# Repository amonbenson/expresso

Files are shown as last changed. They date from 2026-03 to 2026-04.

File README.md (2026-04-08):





# Expresso

An open source USB&ndash;Midi&ndash;Expression pedal converter.

⚠️ Please note: This project is currently under heavy development and not yet functional. ⚠️

✔️ Supports sustain pedals of any polarity<br>
✔️ Supports any kind of three-pin analog expression pedal<br>
✔️ Pedal state can be output to both Din- or USB-Midi<br>
✔️ Can be used as a classic USB-Din-Midi adapter<br>

... to be continued.

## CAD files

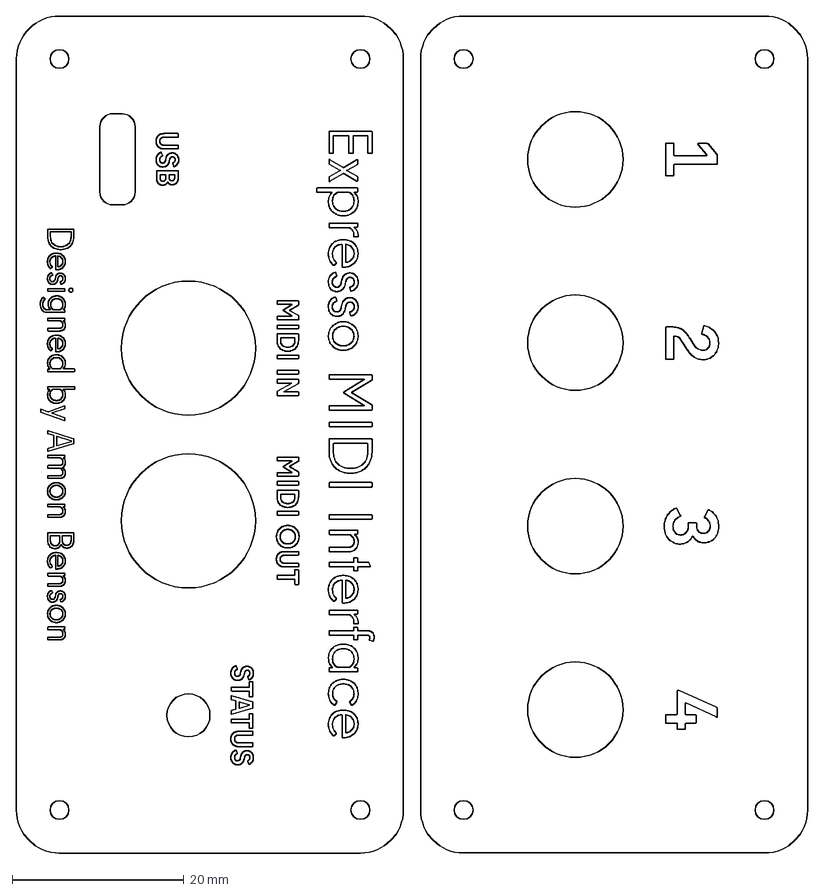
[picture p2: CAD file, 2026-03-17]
hw/enclosure/Expresso Enclosure Laser Cut Parts Projection.dxf
92.0 x 97.3 mm

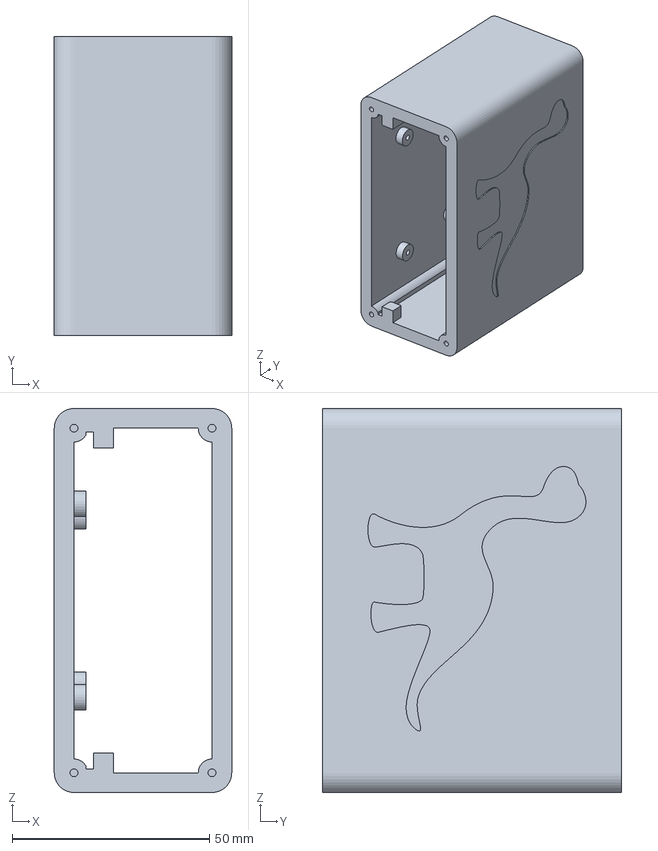
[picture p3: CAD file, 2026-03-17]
hw/enclosure/fabrication/Expresso Enclosure.3mf
45.0 x 75.7 x 97.3 mm

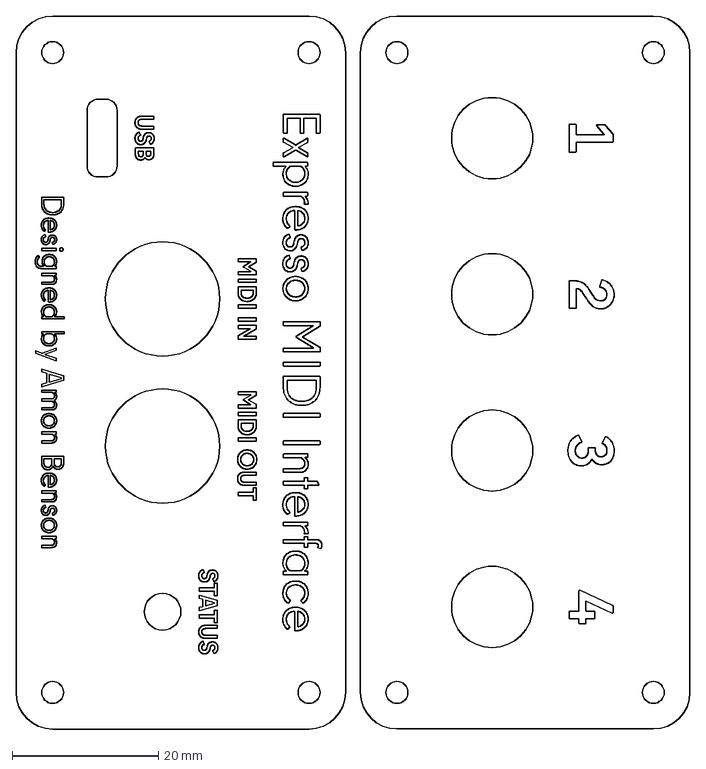
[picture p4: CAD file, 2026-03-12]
hw/Expresso Enclosure Laser Cut Parts Projection.dxf
92.0 x 97.3 mm

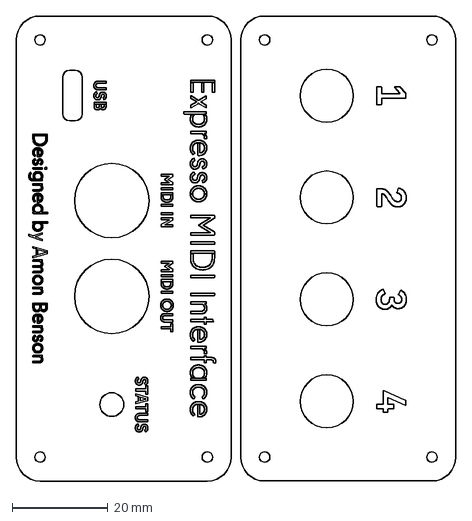
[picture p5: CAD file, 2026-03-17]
hw/enclosure/Expresso Enclosure Laser Cut Parts.dxf
92.0 x 97.3 mm

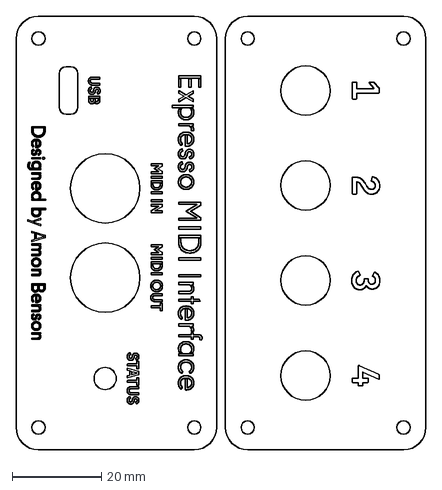
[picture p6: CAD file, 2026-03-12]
hw/Expresso Enclosure Laser Cut Parts.dxf
92.0 x 97.3 mm

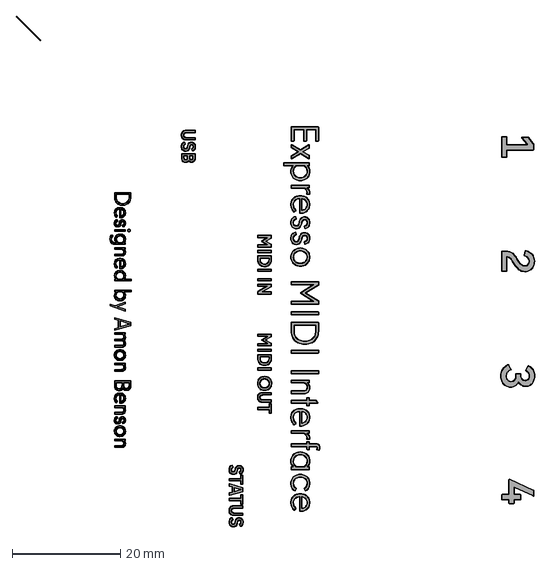
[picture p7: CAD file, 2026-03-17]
hw/enclosure/Expresso Enclosure Laser Cut Engravings.dxf
96.0 x 94.5 mm

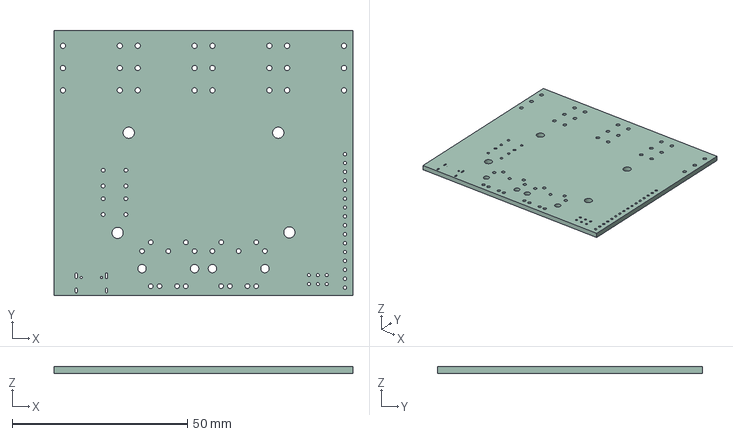
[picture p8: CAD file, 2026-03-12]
hw/Expresso.step
85.3 x 75.7 x 1.87 mm

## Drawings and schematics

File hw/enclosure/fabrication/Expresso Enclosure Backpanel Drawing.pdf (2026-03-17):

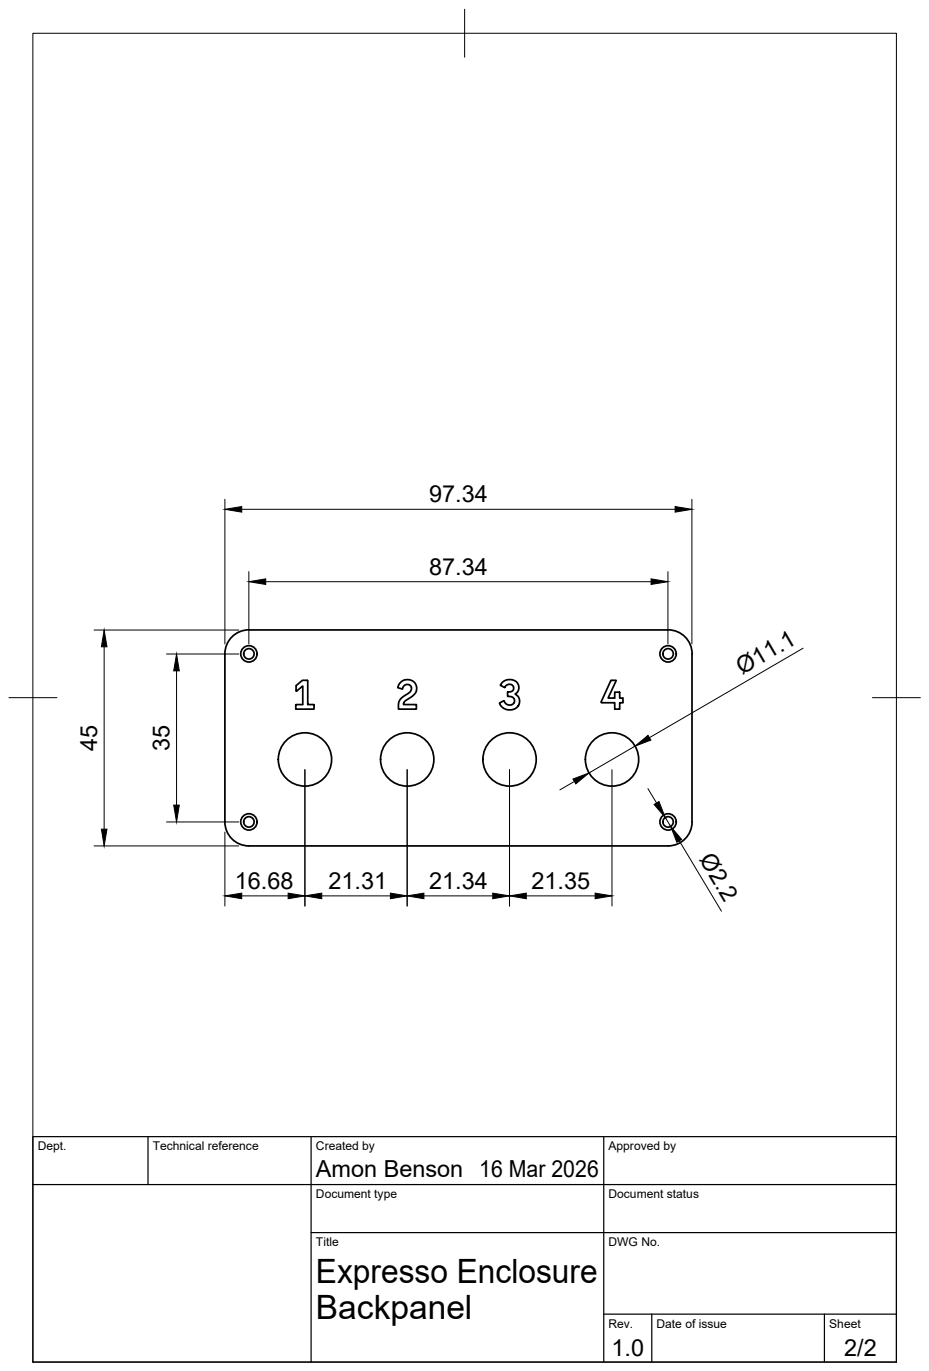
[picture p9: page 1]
Amon Benson 45

Dept. | Technical reference | Created by 16 Mar 2026 | Approved by

Document type | Document status

Title Expresso Enclosure Backpanel | DWG No.

Rev. 1.0 | Date of issue | Sheet 2/2

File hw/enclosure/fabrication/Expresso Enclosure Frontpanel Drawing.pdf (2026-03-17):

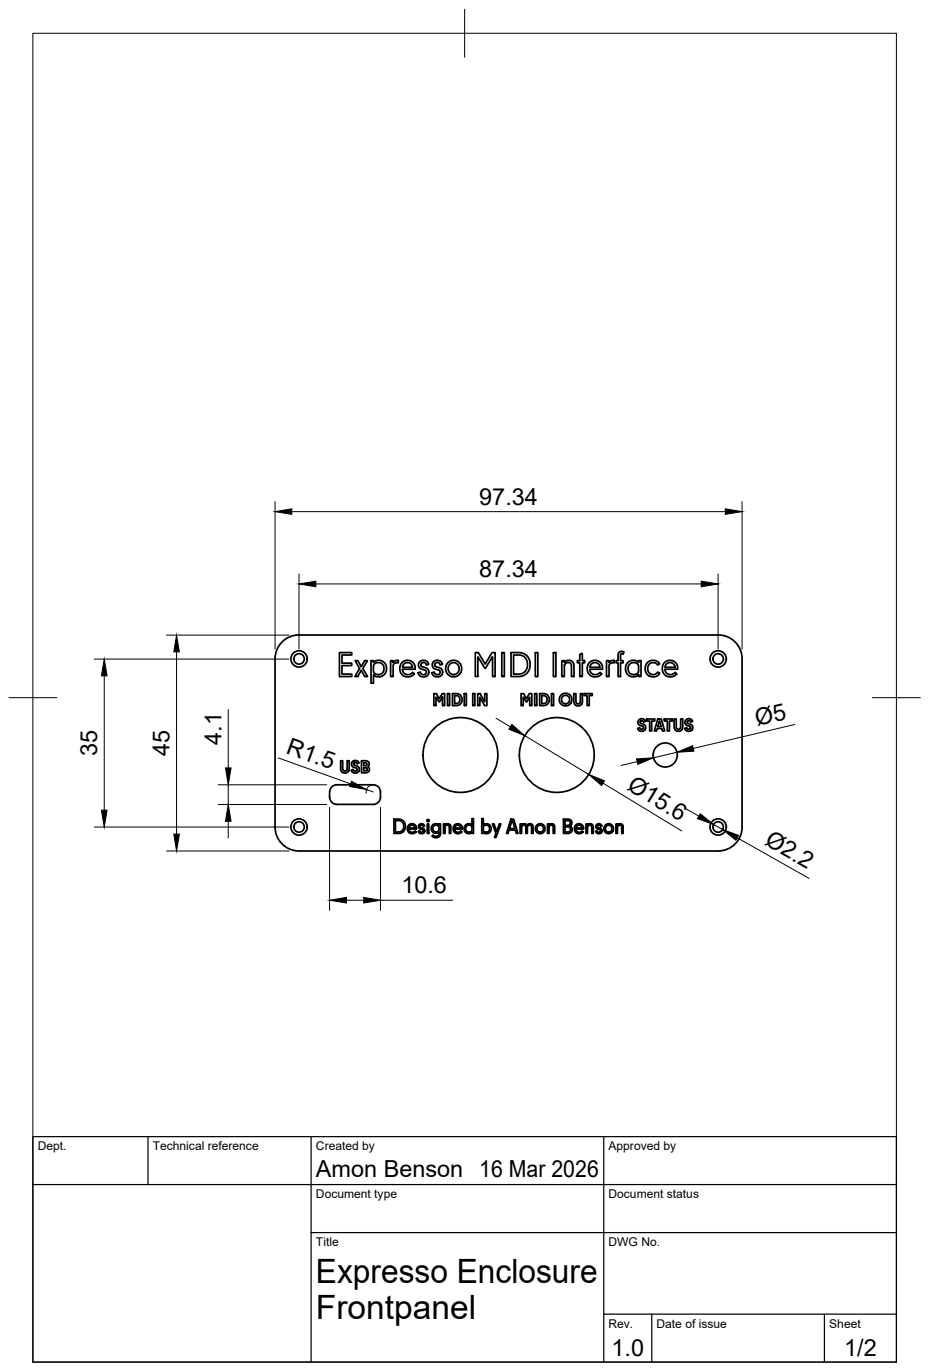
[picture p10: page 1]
Amon Benson 45 Ø15.6 35R1.5

Dept. | Technical reference | Created by 16 Mar 2026 | Approved by

Document type | Document status

Title Expresso Enclosure Frontpanel | DWG No.

Rev. 1.0 | Date of issue | Sheet 1/2

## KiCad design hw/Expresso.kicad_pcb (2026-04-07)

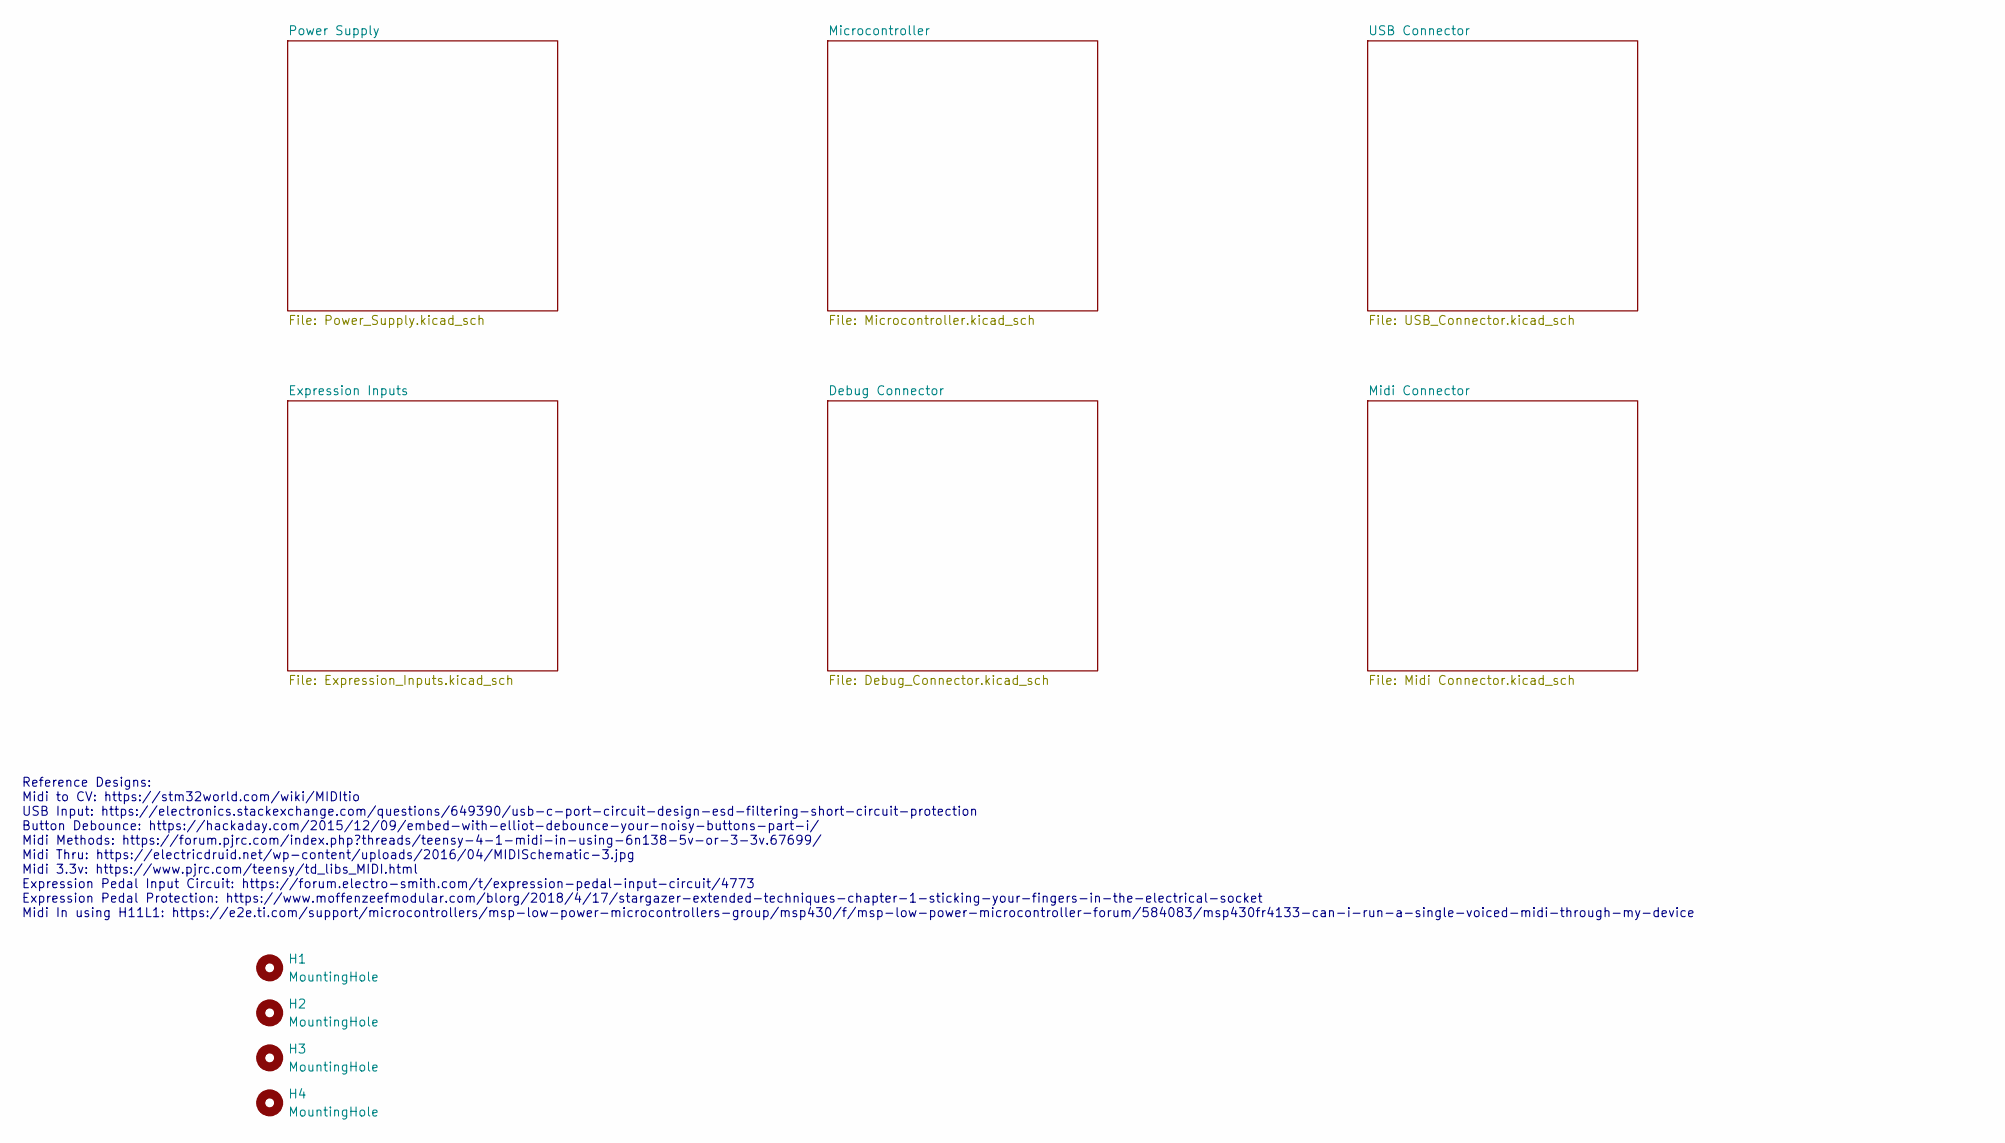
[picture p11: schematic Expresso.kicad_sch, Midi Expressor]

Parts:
H1, H2, H3, H4: MountingHole; MountingHole_3.2mm_M3

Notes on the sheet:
Reference Designs: Midi to CV: https://stm32world.com/wiki/MIDItio USB Input: https://electronics.stackexchange.com/questions/649390/usb-c-port-circuit-design-esd-filtering-short-circuit-protection Button Debounce: https://hackaday.com/2015/12/09/embed-with-elliot-debounce-your-noisy-buttons-part-i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

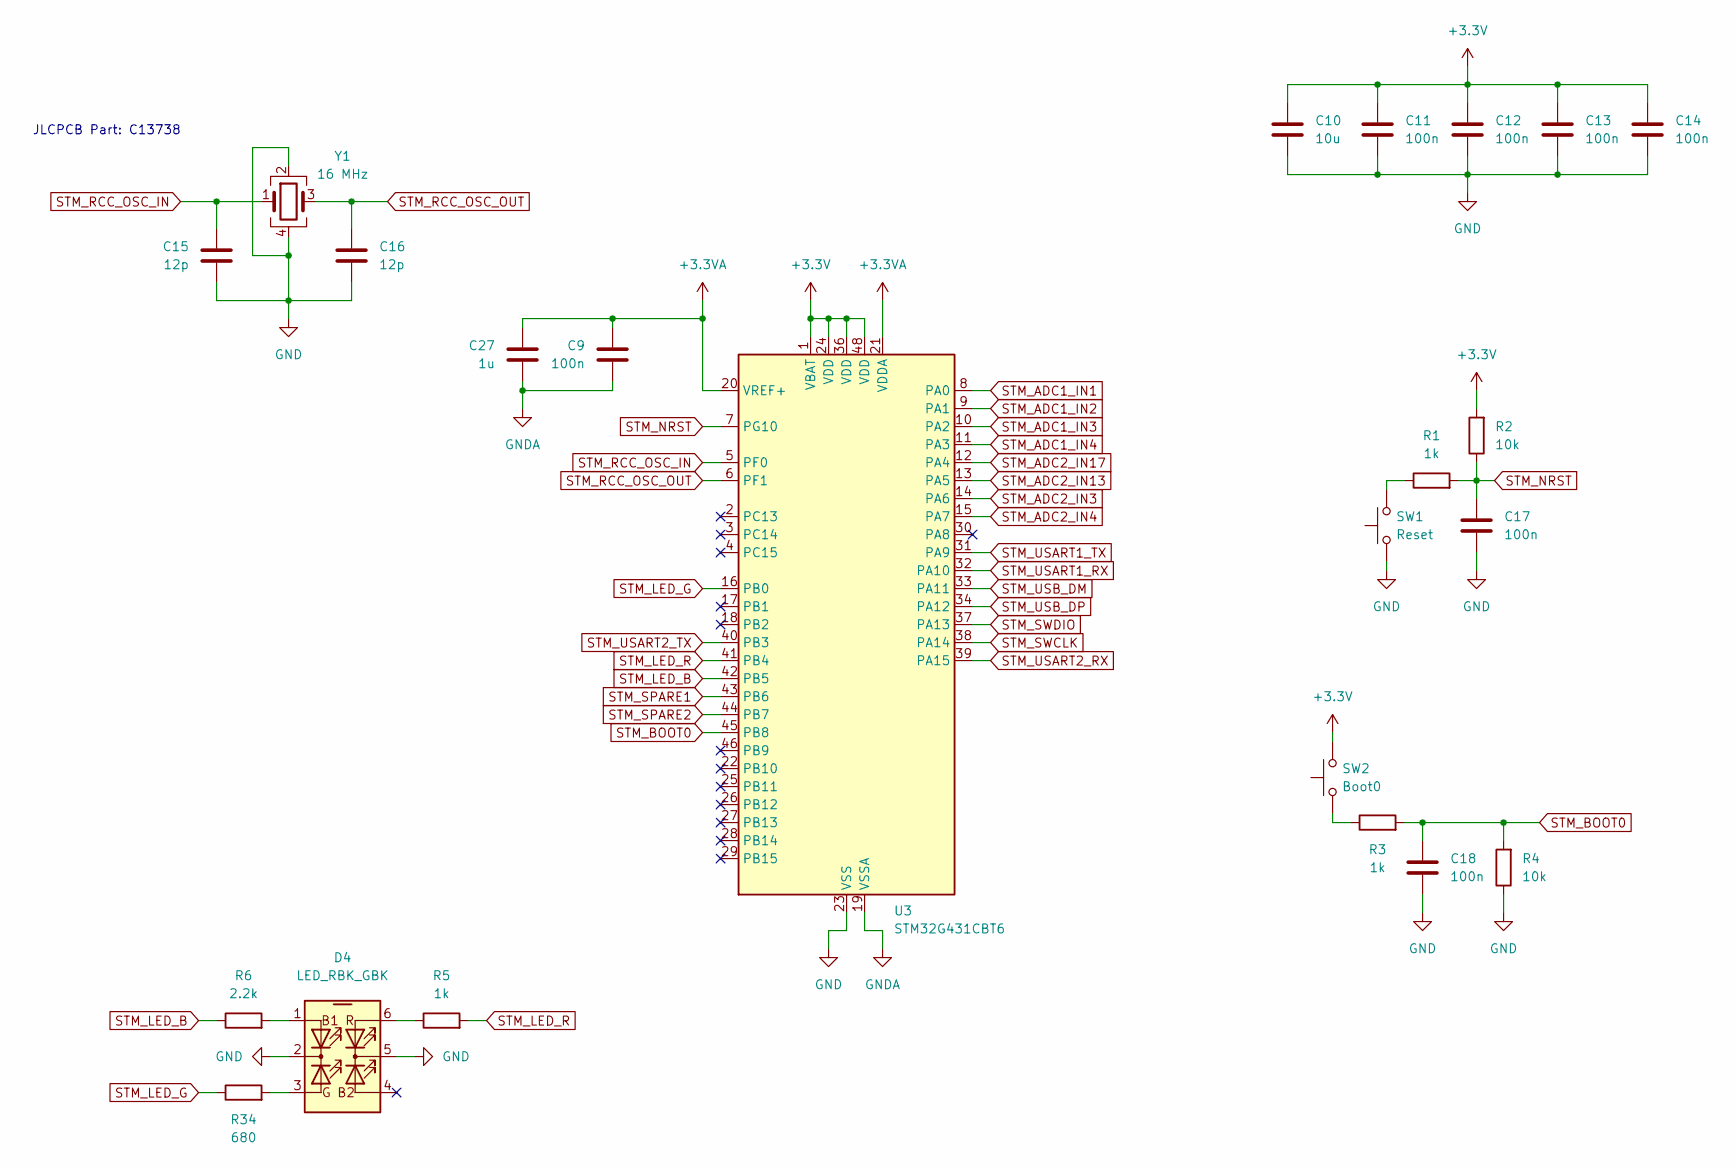
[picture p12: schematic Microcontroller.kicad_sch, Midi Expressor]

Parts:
C9, C11, C12, C13, C14, C17, C18: 100n; C_0603_1608Metric; LCSC C14663
C10: 10u; C_0603_1608Metric; LCSC C19702
C15, C16: 12p; C_0603_1608Metric; LCSC C38523
C27: 1u; C_0603_1608Metric; LCSC C15849
D4: LED_RBK_GBK; LED_D5.0mm_6Pin
R1, R3, R5: 1k; R_0603_1608Metric; LCSC C21190
R2, R4: 10k; R_0603_1608Metric; LCSC C25804
R6: 2.2k; R_0603_1608Metric; LCSC C4190
R34: 680; R_0603_1608Metric; LCSC C23228
SW1: Reset; SW_PUSH_6mm
SW2: Boot0; SW_PUSH_6mm
U3: STM32G431CBT6; LQFP-48_7x7mm_P0.5mm; LCSC C529355
Y1: 16 MHz; Crystal_SMD_3225-4Pin_3.2x2.5mm; LCSC C13738

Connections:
+3.3V: C10.1, C11.1, C12.1, C13.1, C14.1, R2.2, SW2.2, U3.1 (VBAT), U3.24 (VDD), U3.36 (VDD), U3.48 (VDD); also elsewhere on the board
+3.3VA: C9.1, C27.1, U3.20 (VREF+), U3.21 (VDDA); also elsewhere on the board
GND: C10.2, C11.2, C12.2, C13.2, C14.2, C15.2, C16.2, C17.2, C18.2, D4.2 (K1), D4.5 (K2), R4.1, SW1.1, U3.23 (VSS), U3.35 (VSS), U3.47 (VSS), Y1.2, Y1.4; also elsewhere on the board
GNDA: C9.2, C27.2, U3.19 (VSSA); also elsewhere on the board
unnamed: D4.1 (B1A), R6.2
unnamed: D4.3 (GA), R34.2
unnamed: D4.6 (RA), R5.1
unnamed: R1.1, SW1.2
unnamed: R3.1, SW2.1
STM_ADC1_IN1: U3.8 (PA0); also elsewhere on the board
STM_ADC1_IN2: U3.9 (PA1); also elsewhere on the board
STM_ADC1_IN3: U3.10 (PA2); also elsewhere on the board
STM_ADC1_IN4: U3.11 (PA3); also elsewhere on the board
STM_ADC2_IN3: U3.14 (PA6); also elsewhere on the board
STM_ADC2_IN4: U3.15 (PA7); also elsewhere on the board
STM_ADC2_IN13: U3.13 (PA5); also elsewhere on the board
STM_ADC2_IN17: U3.12 (PA4); also elsewhere on the board
STM_BOOT0: C18.1, R3.2, R4.2, U3.45 (PB8)
STM_LED_B: R6.1, U3.42 (PB5)
STM_LED_G: R34.1, U3.16 (PB0)
STM_LED_R: R5.2, U3.41 (PB4)
STM_NRST: C17.1, R1.2, R2.1, U3.7 (PG10); also elsewhere on the board
STM_RCC_OSC_IN: C15.1, U3.5 (PF0), Y1.1
STM_RCC_OSC_OUT: C16.1, U3.6 (PF1), Y1.3
STM_SPARE1: U3.43 (PB6); also elsewhere on the board
STM_SPARE2: U3.44 (PB7); also elsewhere on the board
STM_SWCLK: U3.38 (PA14); also elsewhere on the board
STM_SWDIO: U3.37 (PA13); also elsewhere on the board
STM_USART1_RX: U3.32 (PA10); also elsewhere on the board
STM_USART1_TX: U3.31 (PA9); also elsewhere on the board
STM_USART2_RX: U3.39 (PA15); also elsewhere on the board
STM_USART2_TX: U3.40 (PB3); also elsewhere on the board
STM_USB_DM: U3.33 (PA11); also elsewhere on the board
STM_USB_DP: U3.34 (PA12); also elsewhere on the board

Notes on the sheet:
JLCPCB Part: C13738

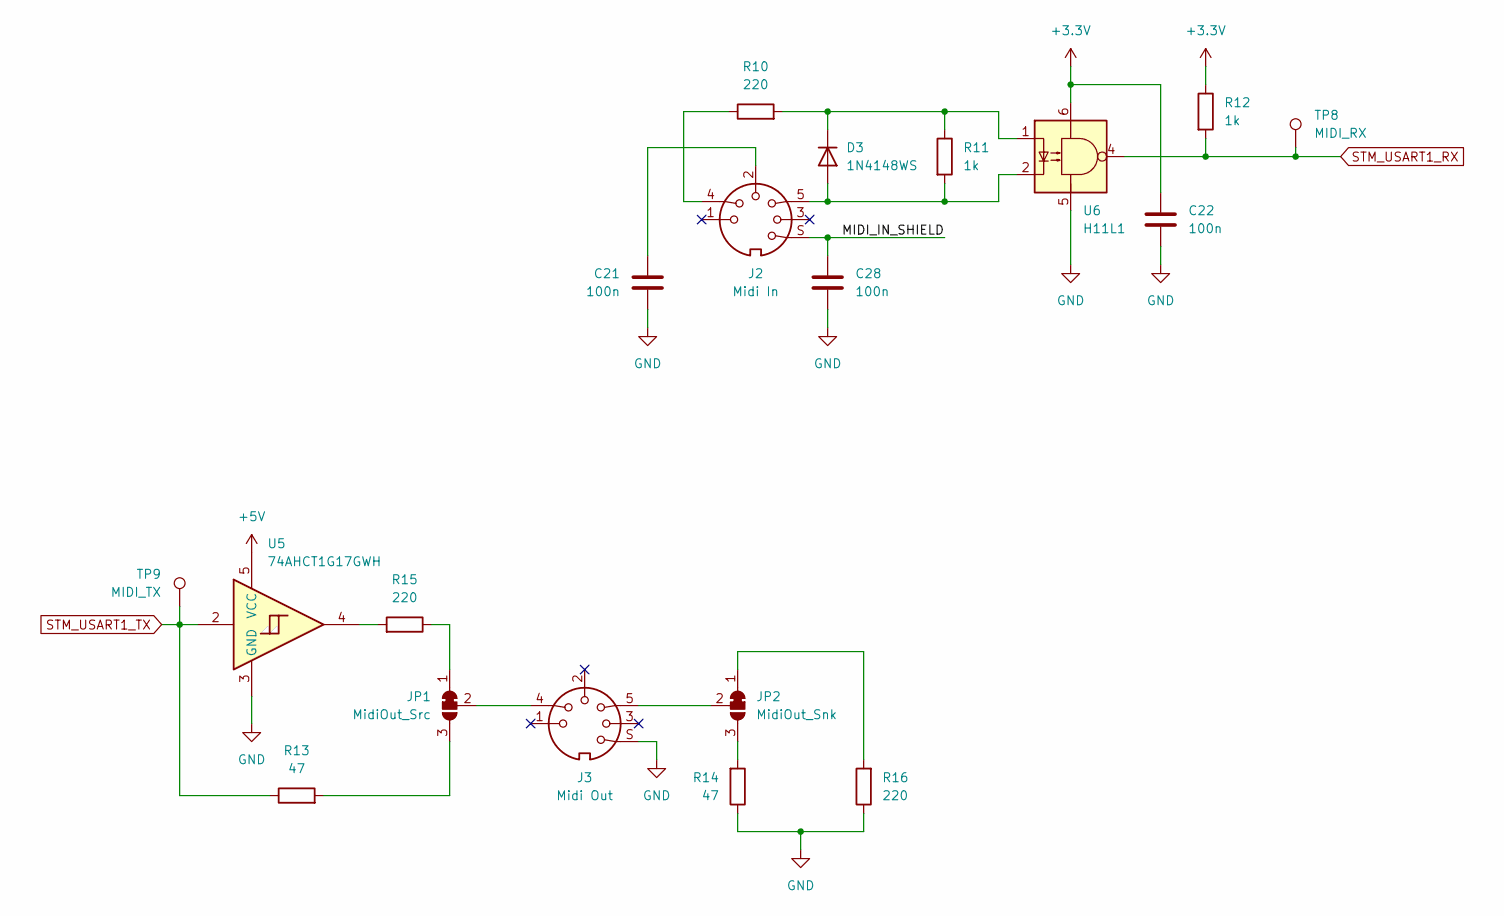
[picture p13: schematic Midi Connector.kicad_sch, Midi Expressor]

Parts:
C21, C22, C28: 100n; C_0603_1608Metric; LCSC C14663
D3: 1N4148WS; D_SOD-323; LCSC C2128
J2: Midi In; DIN5_MIDI_MultiGround
J3: Midi Out; DIN5_MIDI_MultiGround
JP1: MidiOut_Src; SolderJumper-3_P1.3mm_Bridged12_RoundedPad1.0x1.5mm
JP2: MidiOut_Snk; SolderJumper-3_P1.3mm_Bridged12_RoundedPad1.0x1.5mm
R10, R15, R16: 220; R_0603_1608Metric; LCSC C22962
R11, R12: 1k; R_0603_1608Metric; LCSC C21190
R13, R14: 47; R_0603_1608Metric; LCSC C23182
TP8: MIDI_RX; TestPoint_Pad_D2.0mm
TP9: MIDI_TX; TestPoint_Pad_D2.0mm
U5: 74AHCT1G17GWH; SOT-353_SC-70-5; LCSC C554579
U6: H11L1; SOP-6_6.35x8.51mm_P02.54mm; LCSC C899473

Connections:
+3.3V: C22.1, R12.1, U6.6; also elsewhere on the board
+5V: U5.5 (VCC); also elsewhere on the board
/Midi Connector/MIDI_IN_SHIELD: C28.1, J2.S
GND: C21.2, C22.2, C28.2, J3.S, R14.1, R16.1, U5.3 (GND), U6.5; also elsewhere on the board
unnamed: C21.1, J2.2
unnamed: D3.2 (A), J2.5, R11.2, U6.2
unnamed: D3.1 (K), R10.2, R11.1, U6.1
unnamed: J2.4, R10.1
unnamed: JP1.1 (A), R15.1
unnamed: JP1.3 (B), R13.2
unnamed: J3.4, JP1.2 (C)
unnamed: JP2.1 (A), R16.2
unnamed: JP2.3 (B), R14.2
unnamed: J3.5, JP2.2 (C)
unnamed: R15.2, U5.4
STM_USART1_RX: R12.2, TP8.1, U6.4; also elsewhere on the board
STM_USART1_TX: R13.1, TP9.1, U5.2; also elsewhere on the board

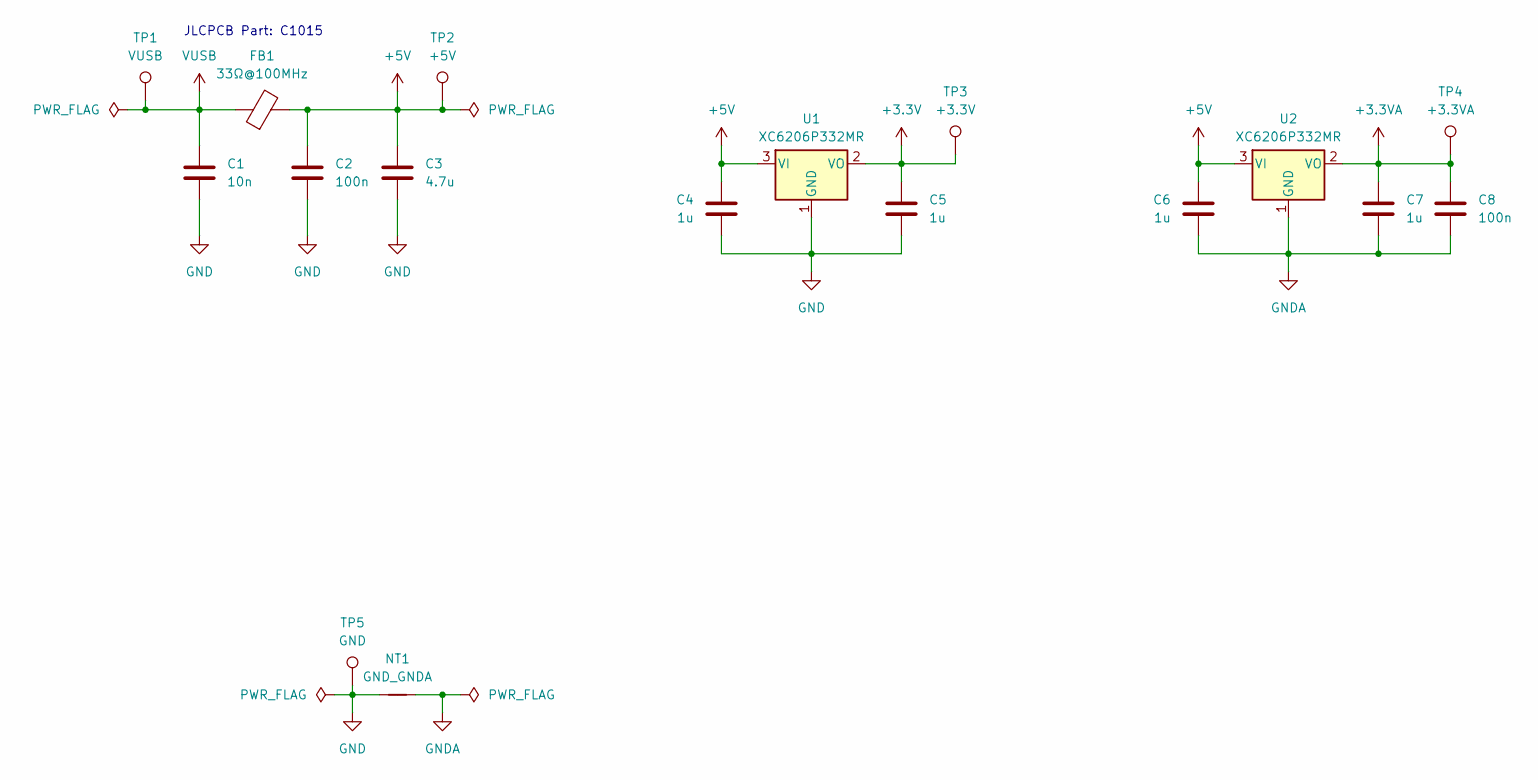
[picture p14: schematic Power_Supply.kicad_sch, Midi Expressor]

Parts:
C1: 10n; C_0603_1608Metric; LCSC C57112
C2, C8: 100n; C_0603_1608Metric; LCSC C14663
C3: 4.7u; C_0603_1608Metric; LCSC C19666
C4, C5, C6, C7: 1u; C_0603_1608Metric; LCSC C15849
FB1: 33Ω@100MHz; L_0805_2012Metric; LCSC C1015
NT1: GND_GNDA; NetTie-2_SMD_Pad0.5mm
TP1: VUSB; TestPoint_Pad_D2.0mm
TP2: +5V; TestPoint_Pad_D2.0mm
TP3: +3.3V; TestPoint_Pad_D2.0mm
TP4: +3.3VA; TestPoint_Pad_D2.0mm
TP5: GND; TestPoint_Pad_D2.0mm
U1, U2: XC6206P332MR; SOT-23-3; LCSC C5446

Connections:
+3.3V: C5.1, TP3.1, U1.2 (VO); also elsewhere on the board
+3.3VA: C7.1, C8.1, TP4.1, U2.2 (VO); also elsewhere on the board
+5V: C2.1, C3.1, C4.1, C6.1, FB1.2, TP2.1, U1.3 (VI), U2.3 (VI); also elsewhere on the board
GND: C1.2, C2.2, C3.2, C4.2, C5.2, NT1.1, TP5.1, U1.1 (GND); also elsewhere on the board
GNDA: C6.2, C7.2, C8.2, NT1.2, U2.1 (GND); also elsewhere on the board
VUSB: C1.1, FB1.1, TP1.1; also elsewhere on the board

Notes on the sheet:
JLCPCB Part: C1015

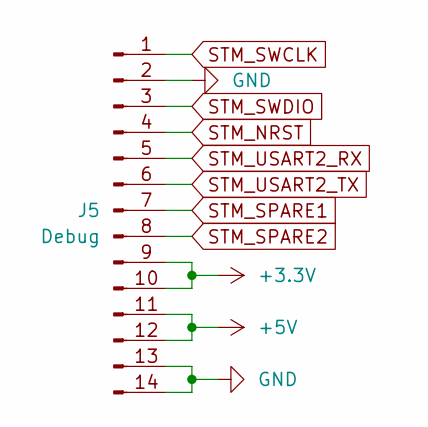
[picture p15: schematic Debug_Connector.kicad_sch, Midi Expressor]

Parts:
J5: Debug; PinHeader_1x14_P2.54mm_Vertical

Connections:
+3.3V: J5.9, J5.10; also elsewhere on the board
+5V: J5.11, J5.12; also elsewhere on the board
GND: J5.2, J5.13, J5.14; also elsewhere on the board
STM_NRST: J5.4; also elsewhere on the board
STM_SPARE1: J5.7; also elsewhere on the board
STM_SPARE2: J5.8; also elsewhere on the board
STM_SWCLK: J5.1; also elsewhere on the board
STM_SWDIO: J5.3; also elsewhere on the board
STM_USART2_RX: J5.5; also elsewhere on the board
STM_USART2_TX: J5.6; also elsewhere on the board

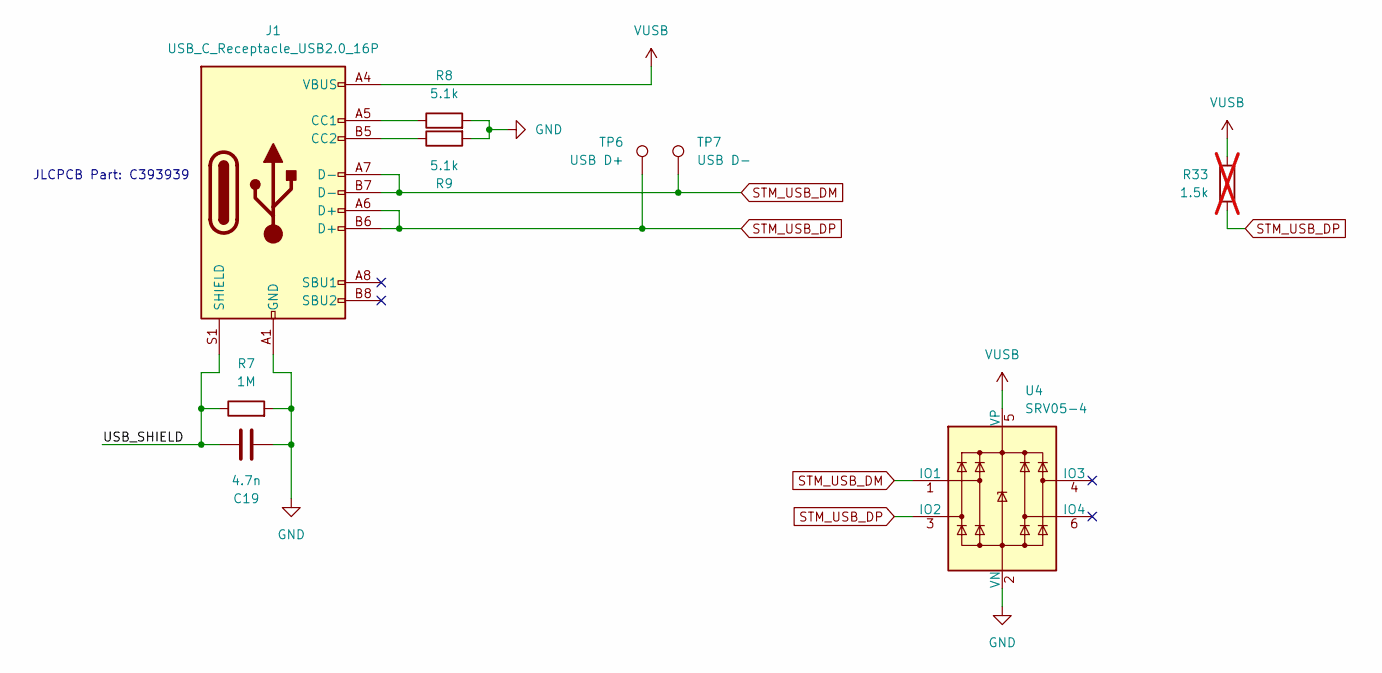
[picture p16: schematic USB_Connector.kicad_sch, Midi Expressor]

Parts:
C19: 4.7n; C_0603_1608Metric; LCSC C53987
J1: USB_C_Receptacle_USB2.0_16P; USB_C_Receptacle_G-Switch_GT-USB-7010ASV; LCSC C393939
R7: 1M; R_0603_1608Metric; LCSC C22935
R8, R9: 5.1k; R_0603_1608Metric; LCSC C23186
R33: 1.5k; R_0603_1608Metric; not fitted
TP6: USB D+; TestPoint_Pad_D2.0mm
TP7: USB D-; TestPoint_Pad_D2.0mm
U4: SRV05-4; SOT-23-6; LCSC C85364

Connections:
/USB Connector/USB_SHIELD: C19.1, J1.S1 (SHIELD), R7.1
GND: C19.2, J1.A1 (GND), J1.A12 (GND), J1.B1 (GND), J1.B12 (GND), R7.2, R8.2, R9.2, U4.2 (VN); also elsewhere on the board
unnamed: J1.A5 (CC1), R8.1
unnamed: J1.B5 (CC2), R9.1
STM_USB_DM: J1.A7 (D-), J1.B7 (D-), TP7.1, U4.1 (IO1); also elsewhere on the board
STM_USB_DP: J1.A6 (D+), J1.B6 (D+), R33.1, TP6.1, U4.3 (IO2); also elsewhere on the board
VUSB: J1.A4 (VBUS), J1.A9 (VBUS), J1.B4 (VBUS), J1.B9 (VBUS), R33.2, U4.5 (VP); also elsewhere on the board

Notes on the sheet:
JLCPCB Part: C393939

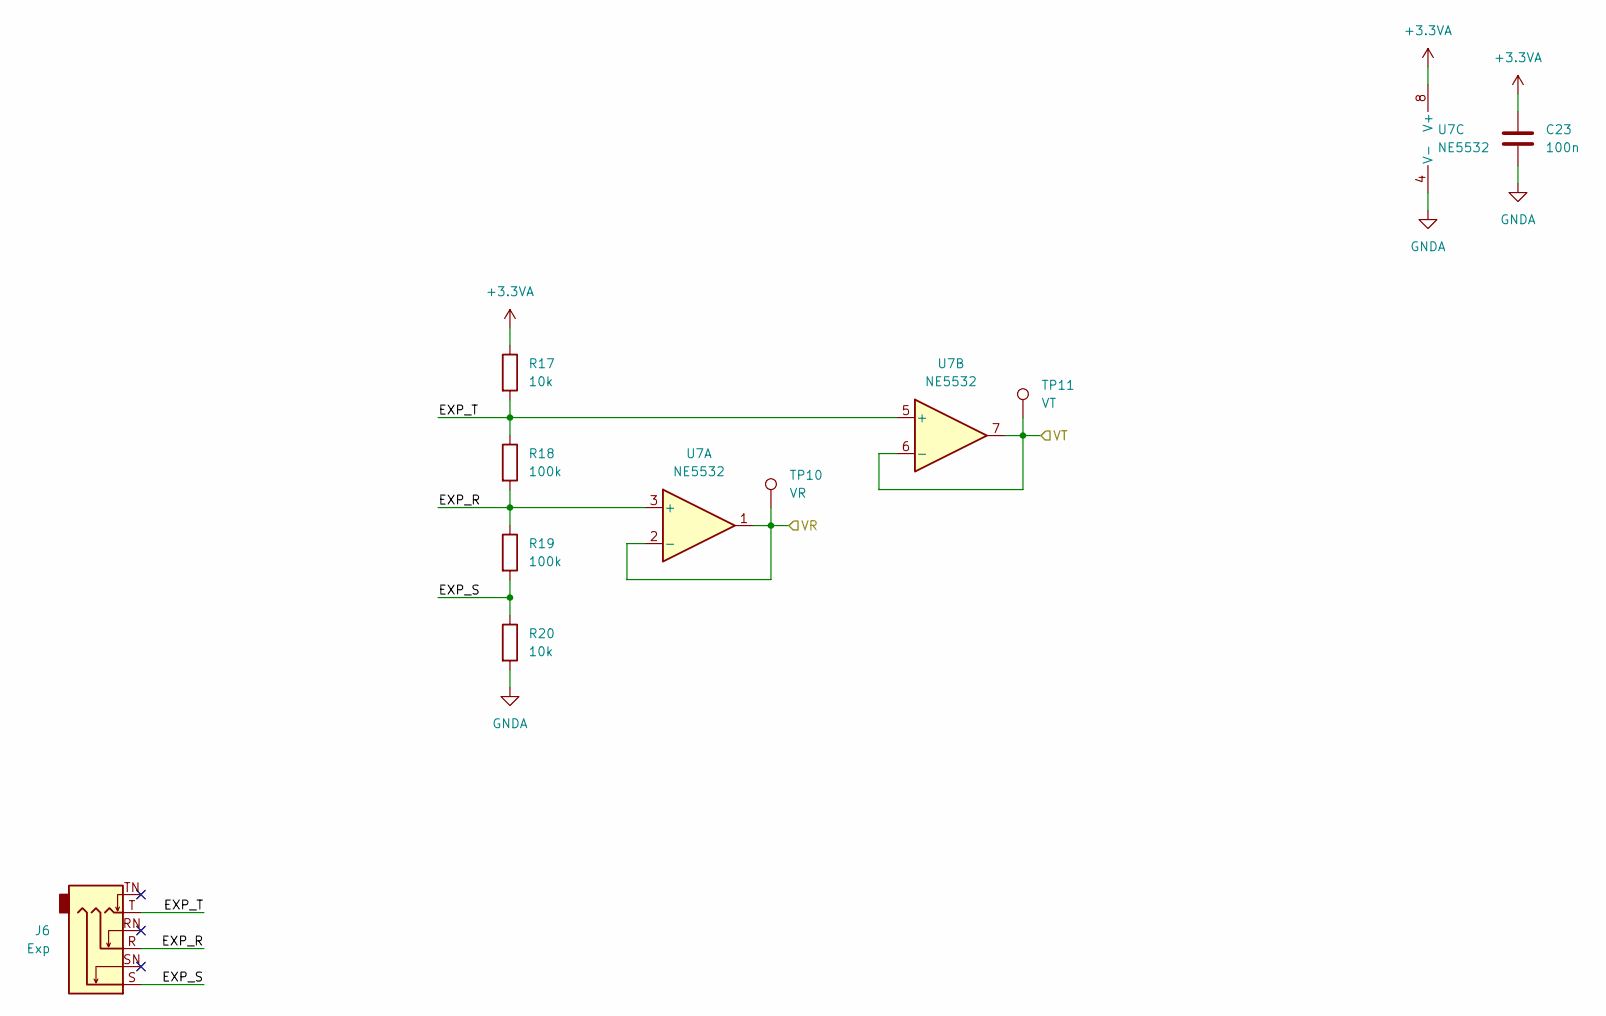
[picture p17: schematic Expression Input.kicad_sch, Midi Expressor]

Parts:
C23: 100n; C_0603_1608Metric; LCSC C14663
J6: Exp; Jack_6.35mm_Neutrik_NMJ6HFD4_Horizontal
R17, R20: 10k; R_0603_1608Metric; LCSC C25804
R18, R19: 100k; R_0603_1608Metric
TP10: VR; TestPoint_Pad_D2.0mm
TP11: VT; TestPoint_Pad_D2.0mm
U7: NE5532; NE5532DR; LCSC C7426

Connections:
+3.3VA: C23.1, R17.1, U7.8 (V+); also elsewhere on the board
/Expression Inputs/Expression Input 1/EXP_R: J6.R, R18.2, R19.1, U7.3 (+)
/Expression Inputs/Expression Input 1/EXP_S: J6.S, R19.2, R20.1
/Expression Inputs/Expression Input 1/EXP_T: J6.T, R17.2, R18.1, U7.5 (+)
GNDA: C23.2, R20.2, U7.4 (V-); also elsewhere on the board
STM_ADC1_IN1: TP10.1, U7.1, U7.2 (-); also elsewhere on the board
STM_ADC1_IN2: TP11.1, U7.6 (-), U7.7; also elsewhere on the board

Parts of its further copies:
C24, C25, C26: 100n; C_0603_1608Metric; LCSC C14663
J7, J8, J9: Exp; Jack_6.35mm_Neutrik_NMJ6HFD4_Horizontal
R21, R24, R25, R28, R29, R32: 10k; R_0603_1608Metric; LCSC C25804
R22, R23, R26, R27, R30, R31: 100k; R_0603_1608Metric
TP12, TP14, TP16: VR; TestPoint_Pad_D2.0mm
TP13, TP15, TP17: VT; TestPoint_Pad_D2.0mm
U8, U9, U10: NE5532; NE5532DR; LCSC C7426

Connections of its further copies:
+3.3VA: C24.1, C25.1, C26.1, R21.1, R25.1, R29.1, U8.8 (V+), U9.8 (V+), U10.8 (V+); also elsewhere on the board
/Expression Inputs/Expression Input 2/EXP_R: J7.R, R22.2, R23.1, U8.3 (+)
/Expression Inputs/Expression Input 2/EXP_S: J7.S, R23.2, R24.1
/Expression Inputs/Expression Input 2/EXP_T: J7.T, R21.2, R22.1, U8.5 (+)
/Expression Inputs/Expression Input 3/EXP_R: J8.R, R26.2, R27.1, U9.3 (+)
/Expression Inputs/Expression Input 3/EXP_S: J8.S, R27.2, R28.1
/Expression Inputs/Expression Input 3/EXP_T: J8.T, R25.2, R26.1, U9.5 (+)
/Expression Inputs/Expression Input 4/EXP_R: J9.R, R30.2, R31.1, U10.3 (+)
/Expression Inputs/Expression Input 4/EXP_S: J9.S, R31.2, R32.1
/Expression Inputs/Expression Input 4/EXP_T: J9.T, R29.2, R30.1, U10.5 (+)
GNDA: C24.2, C25.2, C26.2, R24.2, R28.2, R32.2, U8.4 (V-), U9.4 (V-), U10.4 (V-); also elsewhere on the board
STM_ADC1_IN3: TP12.1, U8.1, U8.2 (-); also elsewhere on the board
STM_ADC1_IN4: TP13.1, U8.6 (-), U8.7; also elsewhere on the board
STM_ADC2_IN3: TP16.1, U10.1, U10.2 (-); also elsewhere on the board
STM_ADC2_IN4: TP17.1, U10.6 (-), U10.7; also elsewhere on the board
STM_ADC2_IN13: TP15.1, U9.6 (-), U9.7; also elsewhere on the board
STM_ADC2_IN17: TP14.1, U9.1, U9.2 (-); also elsewhere on the board

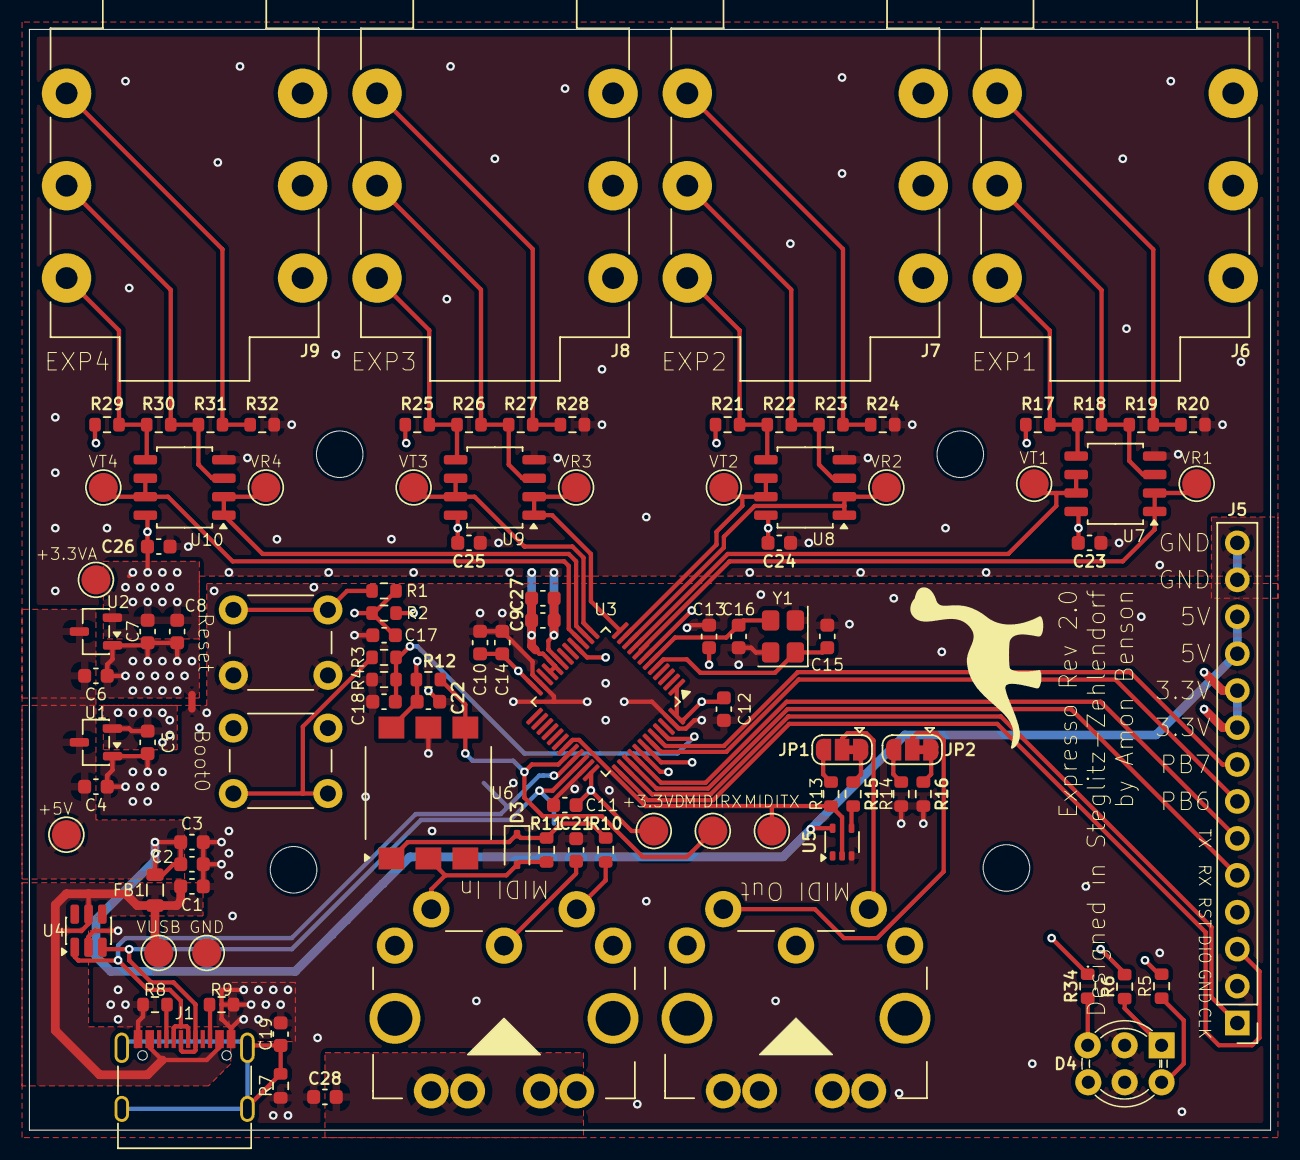
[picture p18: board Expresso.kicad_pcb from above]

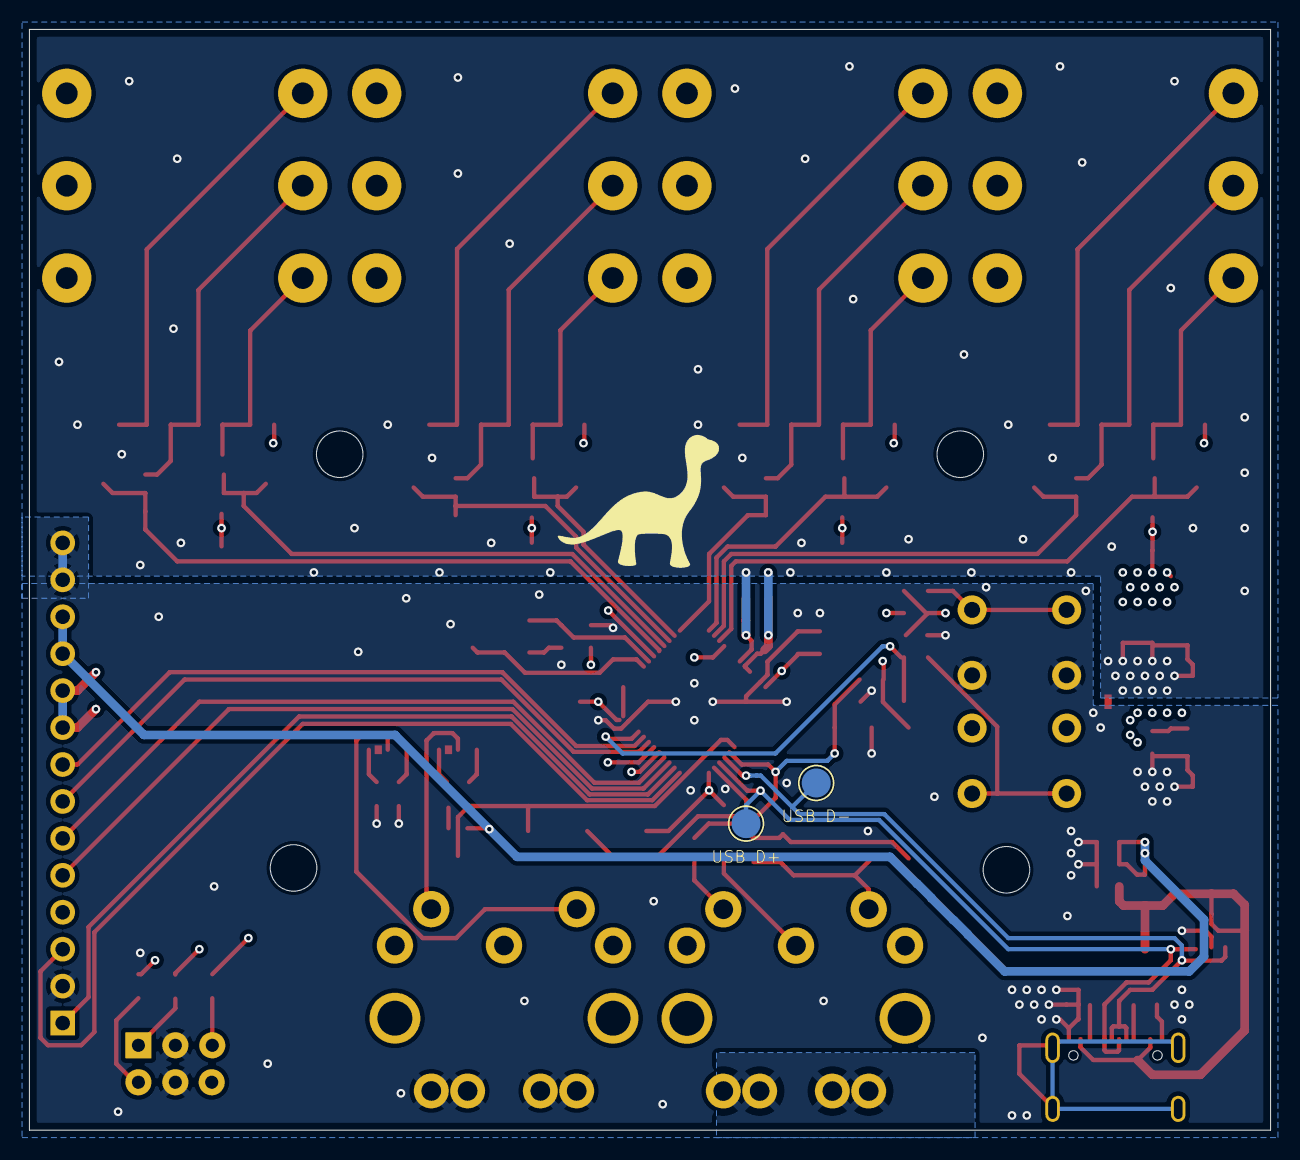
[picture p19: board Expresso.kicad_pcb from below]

Board: 4 copper layers, 85.3 x 75.7 mm, 108 parts (2 on the bottom side), 63 nets.

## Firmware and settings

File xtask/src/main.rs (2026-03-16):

use std::path::{Path, PathBuf};
use std::process::Command;

/// Expresso workspace task runner.
#[derive(argh::FromArgs)]
struct Args {
    #[argh(subcommand)]
    task: Task,
}

#[derive(argh::FromArgs)]
#[argh(subcommand)]
enum Task {
    CheckAll(CheckAll),
    BuildAll(BuildAll),
    TestAll(TestAll),
    FlashFw(FlashFw),
    TestFw(TestFw),
    RunSw(RunSw),
    Cubemx(Cubemx),
}

/// Check lib + firmware + software.
#[derive(argh::FromArgs)]
#[argh(subcommand, name = "check-all")]
struct CheckAll {}

/// Build lib + firmware + software.
#[derive(argh::FromArgs)]
#[argh(subcommand, name = "build-all")]
struct BuildAll {}

/// Test lib + software.
#[derive(argh::FromArgs)]
#[argh(subcommand, name = "test-all")]
struct TestAll {}

/// Build + flash firmware via USB DFU (device must be in DFU mode first).
#[derive(argh::FromArgs)]
#[argh(subcommand, name = "flash-fw")]
struct FlashFw {}

/// Build firmware and run Renode integration tests.
#[derive(argh::FromArgs)]
#[argh(subcommand, name = "test-fw")]
struct TestFw {}

/// Run desktop software in development mode (npm run tauri dev).
#[derive(argh::FromArgs)]
#[argh(subcommand, name = "run-sw")]
struct RunSw {}

/// Open fw/expresso.ioc in STM32CubeMX.
#[derive(argh::FromArgs)]
#[argh(subcommand, name = "cubemx")]
struct Cubemx {}

fn main() {
    let args: Args = argh::from_env();
    match args.task {
        Task::CheckAll(_) => check_all(),
        Task::BuildAll(_) => build_all(),
        Task::TestAll(_) => test_all(),
        Task::FlashFw(_) => flash_fw(),
        Task::TestFw(_) => test_fw(),
        Task::RunSw(_) => run_sw(),
        Task::Cubemx(_) => open_cubemx(),
    }
}

fn build_all() {
    cargo(&["build-lib"]);
    cargo(&["build-fw"]);
    cargo(&["build-sw"]);
}

fn check_all() {
    cargo(&["check-lib"]);
    cargo(&["check-fw"]);
    cargo(&["check-sw"]);
}

fn test_all() {
    cargo(&["test-lib"]);
    cargo(&["test-sw"]);
    cargo(&["test-fw"]);
}

fn test_fw() {
    // Build firmware ELF first.
    cargo(&["build-fw"]);

    let root = workspace_root();

    // STM32CubeProgrammer (and Renode) require a recognised .elf extension.
    let elf_src = root.join("target/thumbv7em-none-eabihf/release/expresso-fw");
    let elf = root.join("target/thumbv7em-none-eabihf/release/expresso-fw.elf");
    std::fs::copy(&elf_src, &elf).expect("failed to copy ELF to .elf");

    let renode_dir = find_renode();
    let python = find_python();
    let run_tests = renode_dir.join("tests/run_tests.py");
    let css = renode_dir.join("tests/robot.css");

    // Write results into target/ so they are covered by the root .gitignore.
    let results_dir = root.join("target/renode-results");
    std::fs::create_dir_all(&results_dir).expect("failed to create renode-results dir");

    let robot_tests_dir = root.join("tests/renode/tests");

    // Collect all .robot files; run_tests.py needs explicit file paths, not a directory.
    let mut robot_files: Vec<PathBuf> = std::fs::read_dir(&robot_tests_dir)
        .unwrap_or_else(|e| panic!("cannot read {}: {e}", robot_tests_dir.display()))
        .filter_map(|e| e.ok())
        .map(|e| e.path())
        .filter(|p| p.extension().and_then(|e| e.to_str()) == Some("robot"))
        .collect();
    robot_files.sort();

    if robot_files.is_empty() {
        eprintln!(
            "error: no .robot files found in {}",
            robot_tests_dir.display()
        );
        std::process::exit(1);
    }

    eprintln!("Running {} Renode test file(s) ...", robot_files.len());

    let status = Command::new(&python)
        .env("PYTHONIOENCODING", "utf-8")
        .arg(&run_tests)
        .arg("--css-file")
        .arg(&css)
        .arg("--robot-framework-remote-server-full-directory")
        .arg(&renode_dir)
        .arg("-r")
        .arg(&results_dir)
        .args(&robot_files)
        .current_dir(&root)
        .status()
        .unwrap_or_else(|e| panic!("failed to run {}: {e}", python.display()));

    if !status.success() {
        eprintln!("Renode tests failed! Results in {}", results_dir.display());
        std::process::exit(status.code().unwrap_or(1));
    }
}

/// Locate the Renode installation directory (the one containing `tests/run_tests.py`).
///
/// Search order:
///   1. `RENODE_DIR` environment variable (CI override).
///   2. Known install locations for the current OS.
fn find_renode() -> PathBuf {
    if let Ok(dir) = std::env::var("RENODE_DIR") {
        let p = PathBuf::from(dir);
        if p.join("tests/run_tests.py").exists() {
            return p;
        }
        eprintln!("warning: RENODE_DIR set but tests/run_tests.py not found there");
    }

    let candidates: &[&str] = if cfg!(windows) {
        &[r"C:\Program Files\Renode"]
    } else if cfg!(target_os = "macos") {
        &["/Applications/Renode.app/Contents/MacOS"]
    } else {
        &["/opt/renode", "/usr/lib/renode"]
    };

    for path in candidates {
        let p = PathBuf::from(path);
        if p.join("tests/run_tests.py").exists() {
            return p;
        }
    }

    eprintln!("error: Renode not found.");
    eprintln!(
        "Install Renode from https://renode.io or set RENODE_DIR to the installation directory."
    );
    std::process::exit(1);
}

/// Locate a Python 3 interpreter that has `robotframework` installed.
///
/// Search order:
///   1. `RENODE_PYTHON` environment variable (CI override).
///   2. `python3` / `python` on PATH (Linux / macOS).
///   3. Known Miniconda / Anaconda / CPython install paths (Windows).
fn find_python() -> PathBuf {
    if let Ok(py) = std::env::var("RENODE_PYTHON") {
        return PathBuf::from(py);
    }

    if !cfg!(windows) {
        for bin in ["python3", "python"] {
            if which(bin).is_some() {
                return PathBuf::from(bin);
            }
        }
        eprintln!("error: Python 3 not found. Install Python 3 and robotframework.");
        std::process::exit(1);
    }

    // Windows: prefer PATH, but skip the Windows Store stub
    // (C:\Users\…\AppData\Local\Microsoft\WindowsApps\python.exe) which just
    // opens the Microsoft Store instead of running Python.
    if let Some(p) = which("python.exe") {
        let path_str = p.to_string_lossy().to_lowercase();
        if !path_str.contains("windowsapps") {
            return PathBuf::from("python.exe");
        }
    }

    // User-profile conda installs.
    if let Ok(profile) = std::env::var("USERPROFILE") {
        for subdir in ["miniconda3", "Miniconda3", "anaconda3", "Anaconda3"] {
            let p = PathBuf::from(&profile).join(subdir).join("python.exe");
            if p.exists() {
                return p;
            }
        }
    }

    // System-wide conda installs.
    for path in &[
        r"C:\ProgramData\miniconda3\python.exe",
        r"C:\ProgramData\Miniconda3\python.exe",
        r"C:\ProgramData\anaconda3\python.exe",
        r"C:\Python313\python.exe",
        r"C:\Python312\python.exe",
        r"C:\Python311\python.exe",
        r"C:\Python310\python.exe",
    ] {
        let p = PathBuf::from(path);
        if p.exists() {
            return p;
        }
    }

    eprintln!("error: Python not found.");
    eprintln!("Install Python 3 (or set RENODE_PYTHON) and run: pip install robotframework");
    std::process::exit(1);
}

fn run_sw() {
    npm(&["install"]);
    npm(&["run", "tauri", "dev"]);
}

fn flash_fw() {
    cargo(&["build-fw"]);

    let root = workspace_root();
    let elf_src = root.join("target/thumbv7em-none-eabihf/release/expresso-fw");
    // STM32CubeProgrammer requires a recognised file extension to detect the format.
    let elf = root.join("target/thumbv7em-none-eabihf/release/expresso-fw.elf");
    std::fs::copy(&elf_src, &elf).expect("failed to copy ELF to .elf");

    let programmer = find_programmer();

    eprintln!("Flashing {} ...", elf.display());
    eprintln!("Make sure the device is in DFU mode (hold BOOT0 high, then reset).");

    let status = Command::new(&programmer)
        .args(["-c", "port=USB1", "-w"])
        .arg(&elf)
        .arg("-v")
        .status()
        .unwrap_or_else(|e| panic!("failed to run {}: {e}", programmer.display()));

    if !status.success() {
        eprintln!("Flashing failed!");
        std::process::exit(status.code().unwrap_or(1));
    }

    eprintln!("Done! The device will boot the new firmware.");
}

fn open_cubemx() {
    let ioc = workspace_root().join("fw/expresso.ioc");
    let cubemx = find_cubemx();

    eprintln!("Opening {} in STM32CubeMX ...", ioc.display());

    let status = Command::new(&cubemx)
        .arg(&ioc)
        .status()
        .unwrap_or_else(|e| panic!("failed to launch {}: {e}", cubemx.display()));

    if !status.success() {
        eprintln!("STM32CubeMX exited with an error.");
        std::process::exit(status.code().unwrap_or(1));
    }
}

/// Locate STM32CubeMX, searching PATH then known install locations.
fn find_cubemx() -> PathBuf {
    let bin = if cfg!(windows) {
        "STM32CubeMX.exe"
    } else {
        "STM32CubeMX"
    };

    if which(bin).is_some() {
        return PathBuf::from(bin);
    }

    let candidates: &[&str] = if cfg!(windows) {
        &[
            r"C:\ST\STM32CubeMX\STM32CubeMX.exe",
            r"C:\ST\STM32CubeCLT\STM32CubeMX\STM32CubeMX.exe",
            r"C:\Program Files\STMicroelectronics\STM32Cube\STM32CubeMX\STM32CubeMX.exe",
        ]
    } else if cfg!(target_os = "macos") {
        &[
            "/Applications/STMicroelectronics/STM32CubeMX.app/Contents/MacOs/STM32CubeMX",
            "/Applications/STM32CubeMX.app/Contents/MacOs/STM32CubeMX",
        ]
    } else {
        // Linux / WSL
        &[
            "/opt/ST/STM32CubeMX/STM32CubeMX",
            "/usr/local/STM32CubeMX/STM32CubeMX",
        ]
    };

    for path in candidates {
        if Path::new(path).exists() {
            return PathBuf::from(path);
        }
    }

    eprintln!("error: STM32CubeMX not found.");
    eprintln!("Install STM32CubeMX and make sure it is in PATH.");
    std::process::exit(1);
}

/// Locate STM32_Programmer_CLI, searching PATH then known install locations.
fn find_programmer() -> PathBuf {
    // Check PATH first (works if the user added it themselves)
    let bin = if cfg!(windows) {
        "STM32_Programmer_CLI.exe"
    } else {
        "STM32_Programmer_CLI"
    };

    if which(bin).is_some() {
        return PathBuf::from(bin);
    }

    // Fall back to known install locations per OS
    let candidates: &[&str] = if cfg!(windows) {
        &[
            r"C:\ST\STM32CubeCLT\STM32CubeProgrammer\bin\STM32_Programmer_CLI.exe",
            r"C:\Program Files\STMicroelectronics\STM32Cube\STM32CubeProgrammer\bin\STM32_Programmer_CLI.exe",
        ]
    } else if cfg!(target_os = "macos") {
        &[
            "/Applications/STMicroelectronics/STM32Cube/STM32CubeProgrammer/STM32CubeProgrammer.app/Contents/MacOs/bin/STM32_Programmer_CLI",
        ]
    } else {
        // Linux / WSL
        &[
            "/opt/stm32cubeprogrammer/bin/STM32_Programmer_CLI",
            "/usr/local/bin/STM32_Programmer_CLI",
        ]
    };

    for path in candidates {
        if Path::new(path).exists() {
            return PathBuf::from(path);
        }
    }

    eprintln!("error: STM32_Programmer_CLI not found.");
    eprintln!("Install STM32CubeProgrammer and make sure it is in PATH.");
    std::process::exit(1);
}

/// Check if a binary exists anywhere on PATH.
fn which(bin: &str) -> Option<PathBuf> {
    std::env::var_os("PATH").and_then(|path| {
        std::env::split_paths(&path).find_map(|dir| {
            let full = dir.join(bin);
            full.is_file().then_some(full)
        })
    })
}

/// Return the workspace root (parent of the directory containing this xtask).
fn workspace_root() -> PathBuf {
    // CARGO_MANIFEST_DIR is set by cargo and points to xtask/
    let manifest = PathBuf::from(env!("CARGO_MANIFEST_DIR"));
    manifest
        .parent()
        .expect("xtask must be inside workspace")
        .to_owned()
}

fn npm(args: &[&str]) {
    // On Windows npm is a batch script (npm.cmd), not a plain executable.
    let bin = if cfg!(windows) { "npm.cmd" } else { "npm" };
    let status = Command::new(bin)
        .args(args)
        .current_dir(workspace_root().join("sw"))
        .status()
        .expect("failed to run npm");
    if !status.success() {
        std::process::exit(status.code().unwrap_or(1));
    }
}

fn cargo(args: &[&str]) {
    let status = cargo_cmd()
        .args(args)
        .status()
        .expect("failed to run cargo");
    if !status.success() {
        std::process::exit(status.code().unwrap_or(1));
    }
}

fn cargo_cmd() -> Command {
    // Reuse the same cargo binary that invoked us
    let cargo = std::env::var_os("CARGO").unwrap_or_else(|| "cargo".into());
    let mut cmd = Command::new(cargo);
    // Run from the workspace root so relative paths are correct
    cmd.current_dir(workspace_root());
    cmd
}

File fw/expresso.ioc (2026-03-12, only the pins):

Mcu.UserName=STM32G431CBTx
PA0.Signal=ADC1_IN1
PA1.Signal=ADC1_IN2
PA10.Signal=USART1_RX
PA11.Signal=USB_DM
PA12.Signal=USB_DP
PA13.Signal=SYS_JTMS-SWDIO
PA14.Signal=SYS_JTCK-SWCLK
PA15.Signal=USART2_RX
PA2.Signal=ADC1_IN3
PA3.Signal=ADC1_IN4
PA4.Signal=ADC2_IN17
PA5.Signal=ADC2_IN13
PA6.Signal=ADC2_IN3
PA7.Signal=ADC2_IN4
PA9.Signal=USART1_TX
PB0.GPIO_Label=LED_B
PB0.Signal=S_TIM3_CH3
PB3.Signal=USART2_TX
PB4.GPIO_Label=LED_R
PB4.Signal=S_TIM3_CH1
PB5.GPIO_Label=LED_G
PB5.Signal=S_TIM3_CH2
PB6.GPIO_Label=GPIO_SPARE1
PB6.Signal=GPIO_Input
PB7.GPIO_Label=GPIO_SPARE2
PB7.Signal=GPIO_Input
PF0-OSC_IN.Signal=RCC_OSC_IN
PF1-OSC_OUT.Signal=RCC_OSC_OUT

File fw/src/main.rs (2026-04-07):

#![no_std]
#![no_main]

pub mod collector;
mod config;
mod din_midi;
mod expression;
mod flash_store;
mod router;
mod status_led;
pub mod types;
mod usb_midi;

use core::cell::RefCell;
use embassy_executor::Spawner;
use embassy_stm32::adc::{Adc, AdcChannel, AdcConfig};
use embassy_stm32::rcc::mux::{Adcsel, Clk48sel};
use embassy_stm32::rcc::{
    Hse, HseMode, Pll, PllMul, PllPDiv, PllPreDiv, PllQDiv, PllRDiv, PllSource,
};
use embassy_stm32::time::Hertz;
use embassy_stm32::usart::Uart;
use embassy_stm32::{Config, bind_interrupts, peripherals, usart, usb};
use embassy_sync::blocking_mutex::Mutex;
use embassy_sync::channel::Channel;
use embassy_sync::pubsub::PubSubChannel;
use expresso::settings::Settings;
use static_cell::StaticCell;
use types::*;

use {defmt_rtt as _, panic_probe as _};

bind_interrupts!(struct Irqs {
    USB_LP => usb::InterruptHandler<peripherals::USB>;
    USART1 => usart::InterruptHandler<peripherals::USART1>;
});

// ---- Static channels ----

// Architecture:
// ┌────────────┐     ┌──────────┐     ┌────────────┐
// │  USB-MIDI  ├────►│          │────►│  USB-MIDI  │
// └────────────┘     │          │     └────────────┘
// ┌────────────┐     │          │     ┌────────────┐
// │  DIN-MIDI  ├────►│  Router  │────►│  DIN-MIDI  │
// └────────────┘     │          │     └────────────┘
// ┌────────────┐     │          │
// │ Expression ├────►│          │
// └────────────┘     └──────────┘
//
// All tasks also send StatusEvents to the LED task:
// ┌──────────┐
// │ USB-MIDI ├──┐
// ├──────────┤  │   ┌─────────┐
// │ DIN-MIDI ├──┼──►│   LED   │
// ├──────────┤  │   └─────────┘
// │   Expr.  ├──┘
// └──────────┘

static TO_ROUTER: InMsgChannel = Channel::new();

static ROUTER_TO_USB: MsgChannel = Channel::new();
static ROUTER_TO_DIN: MsgChannel = Channel::new();

static STATUS_CHANNEL: StatusChannel = PubSubChannel::new();

#[embassy_executor::main]
async fn main(spawner: Spawner) {
    let mut config = Config::default();
    // Enable external crystal oscillator at 16 MHz
    config.rcc.hse = Some(Hse {
        freq: Hertz(16_000_000),
        mode: HseMode::Oscillator,
    });
    // Configure PLL: HSE 16MHz -> /1 -> ×12 = 192 MHz VCO -> /4 = 48 MHz for ADC12
    config.rcc.pll = Some(Pll {
        source: PllSource::HSE,
        prediv: PllPreDiv::DIV1,
        mul: PllMul::MUL12,
        divp: Some(PllPDiv::DIV4),
        divq: Some(PllQDiv::DIV4), // 192MHz / 4 = 48MHz -> USB
        divr: Some(PllRDiv::DIV2), // 192MHz / 2 = 96MHz -> PLLCLK (unused)
    });
    config.rcc.mux.adc12sel = Adcsel::PLL1_P;
    config.rcc.mux.clk48sel = Clk48sel::PLL1_Q;

    let p = embassy_stm32::init(config);

    static SETTINGS: StaticCell<SettingsMutex> = StaticCell::new();
    let initial_settings = flash_store::load().unwrap_or_default();
    let settings = SETTINGS.init(Mutex::new(RefCell::new(initial_settings)));

    // Create the two subscribers before spawning tasks that need them.
    let led_sub = STATUS_CHANNEL.subscriber().unwrap();
    let usb_status_sub = STATUS_CHANNEL.subscriber().unwrap();

    // Fire Power(true) first so the LED lights up as early as possible.
    // The event sits in the subscriber queues until each task processes it.
    if let Ok(p) = STATUS_CHANNEL.dyn_publisher() {
        p.publish_immediate(StatusEvent::Power(true));
    }

    // Status LED — PB4 (R), PB5 (G), PB0 (B) via TIM3 PWM
    spawner
        .spawn(status_led::task(
            p.TIM3, p.PB4, p.PB5, p.PB0, led_sub, settings,
        ))
        .unwrap();

    // USB MIDI
    let (usb_dev, midi_class) = usb_midi::build(p.USB, p.PA12, p.PA11);
    spawner.spawn(usb_midi::device_task(usb_dev)).unwrap();
    spawner
        .spawn(usb_midi::io_task(
            midi_class,
            p.FLASH,
            ROUTER_TO_USB.receiver(),
            TO_ROUTER.sender(),
            settings,
            &STATUS_CHANNEL,
            usb_status_sub,
        ))
        .unwrap();

    // DIN MIDI
    let uart_config = {
        let mut c = usart::Config::default();
        c.baudrate = 31250;
        c
    };
    let uart = Uart::new(
        p.USART1,
        p.PA10,
        p.PB6, // TODO: Only for rev 1.0, revert to PA9 later
        Irqs,
        p.DMA1_CH4,
        p.DMA1_CH5,
        uart_config,
    )
    .unwrap();
    spawner
        .spawn(din_midi::task(
            uart,
            ROUTER_TO_DIN.receiver(),
            TO_ROUTER.sender(),
            &STATUS_CHANNEL,
        ))
        .unwrap();

    // Expression Pedals
    // Jack pin mapping:
    //   Jack 0 — PA0 (V_ring), PA1 (V_tip) -> ADC1
    //   Jack 1 — PA2 (V_ring), PA3 (V_tip) -> ADC1
    //   Jack 2 — PA4 (V_ring), PA5 (V_tip) -> ADC2
    //   Jack 3 — PA6 (V_ring), PA7 (V_tip) -> ADC2
    let adc1 = Adc::new(p.ADC1, AdcConfig::default());
    let adc2 = Adc::new(p.ADC2, AdcConfig::default());
    spawner
        .spawn(expression::task(
            adc1,
            adc2,
            [
                (p.PA0.degrade_adc(), p.PA1.degrade_adc()),
                (p.PA2.degrade_adc(), p.PA3.degrade_adc()),
            ],
            [
                (p.PA4.degrade_adc(), p.PA5.degrade_adc()),
                (p.PA6.degrade_adc(), p.PA7.degrade_adc()),
            ],
            TO_ROUTER.sender(),
            settings,
            &STATUS_CHANNEL,
        ))
        .unwrap();

    // Router
    spawner
        .spawn(router::task(
            TO_ROUTER.receiver(),
            ROUTER_TO_USB.sender(),
            ROUTER_TO_DIN.sender(),
            settings,
        ))
        .unwrap();

    core::future::pending::<()>().await
}

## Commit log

2026-01-11 rework channel_strip to update with a single message
    [main.rs]
2026-01-13 added hardware directory and main workspace files
    [BOM-Midi Expressor.csv, Debug_Connector.kicad_sch, Expression Input.kicad_sch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]
2026-01-14 updated hardware issues for PBC revision 2
    [Expression Input.kicad_sch, Midi Connector.kicad_sch, Midi Expressor.kicad_pcb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]
2026-03-03 huge schematic rework
    [Expression Input.kicad_sch, Expression_Inputs.kicad_sch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]
2026-03-03 added new pcb design, ERC errors not fixed yet
    [Expression Input.kicad_sch, Expresso.kicad_pcb, Expresso.kicad_sch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]
2026-03-03 saved kicad project
2026-03-04 small PCB updates for casing design
    [Expresso.kicad_pcb, Expresso.kicad_sch]
2026-03-04 removed unused ADC pin
2026-03-04 updates to hardware layer
    [Expression_Inputs.kicad_sch, Expresso.kicad_pcb, Microcontroller.kicad_sch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]
2026-03-04 added basic adc example
2026-03-04 updated midi device layout
2026-03-04 more progress, though not working atm.
    [main.rs, usb_midi.rs]
2026-03-05 updated midi circuit to use 3.3V logic level
    [Expresso.kicad_pcb, Midi Connector.kicad_sch]
2026-03-05 added resistance calculation formulas
2026-03-05 restructured midi encoders/decoders into multiple files
2026-03-07 added usb/din midi connectors and specific tests
2026-03-07 added temporary fallback uart output pin
2026-03-08 replaced const generic by a global constant
    [expression.rs]
2026-03-08 replaced component with two seperate midi traits
    [din_midi.rs, expression.rs]
2026-03-10 removed MIDI Thru and updated Connector positioning
    [Expresso-CuBottom.gbr, Expresso-CuIn1.gbr, Expresso-CuIn2.gbr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]
2026-03-11 updated PCB thickness, added 3d model file
    [Expresso.kicad_pcb, Expresso.step]
2026-03-11 updated connector positions and added new RGB led
    [Expresso Enclosure Laser Cut Parts Raw.dxf, Expresso Enclosure Laser Cut Parts.dxf, Expresso.kicad_pcb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]
2026-03-12 updated front panel designs
    [Expresso Enclosure Laser Cut Parts Projection.dxf, Expresso Enclosure Laser Cut Parts Raw.dxf, Expresso Enclosure Laser Cut Parts.dxf]
2026-03-12 more updates to front panel
    [Expresso Enclosure Laser Cut Parts.dxf]
2026-03-12 added status led in firmware, currently untested
2026-03-12 added new LED traces to hardware
    [Debug_Connector.kicad_sch, Expresso.kicad_pcb, Microcontroller.kicad_sch]
2026-03-13 fixed firmware boot issue
    [din_midi.rs, expression.rs, main.rs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]
2026-03-15 switched to pre-built renode image
2026-03-16 fixed a bug where a running status message would be modified
    [din.rs, main.rs]
2026-03-17 added final production files for version 2
    [BOM-Midi Expressor.csv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]
2026-04-07 fixed input range issue
    [Expression Input.kicad_sch, Expression_Inputs.kicad_sch, Expresso.kicad_pcb]
